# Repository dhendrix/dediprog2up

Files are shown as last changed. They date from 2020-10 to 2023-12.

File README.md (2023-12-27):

# dediprog2up

This is an adapter intended to make firmware development easier on UP Xtreme
and UP Squared motherboards using Dediprog SF600 and EM100.

This project started as I was thinking about playing with the system firmware
(BIOS) on the UP Xtreme and trying to do a coreboot port. I had limited success
at creating a custom cable with a 12-pin header on one side and a 20-pin header
on the other to fit on a [Dediprog
ADP-SF600-254-TO-127-CB](https://www.dediprog.com/product/ADP-SF600-254-TO-127-CB).
It was difficult to split a fine-pitch ribbon cable and when I finally got one
working it could only operate at 1.5MHz.

Using this adapter board I was able to read and write the ROM using an SF600 at
24MHz, which is also fast enough to use an EM100 for SPI flash emulation.

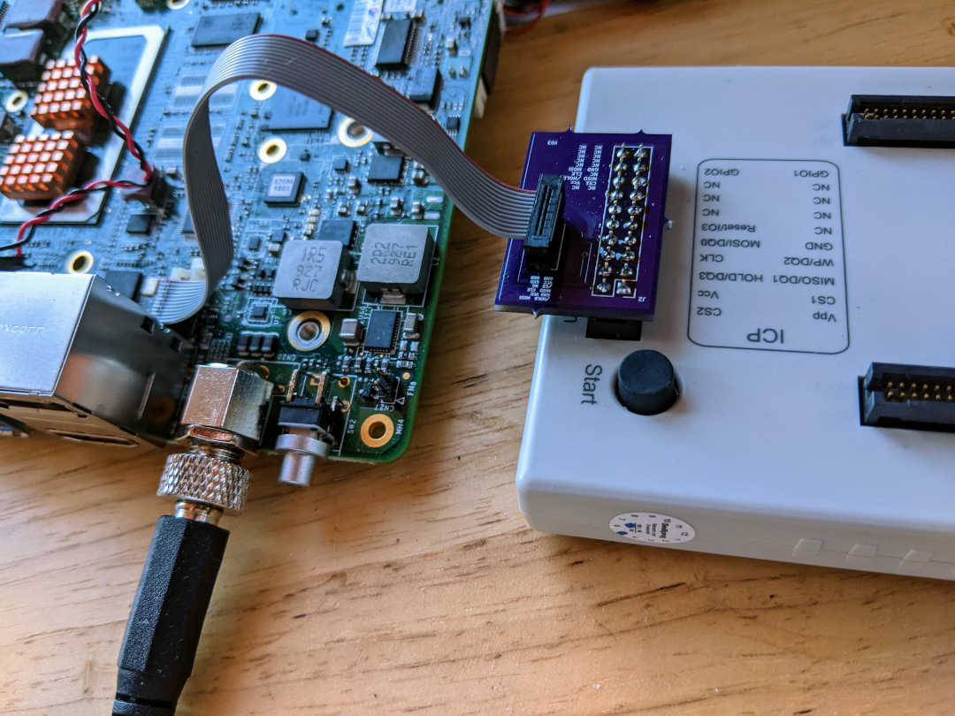
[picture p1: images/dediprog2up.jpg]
Action shot


## Pinout
### UP

The UP wiki has a good diagram of the header:
https://wiki.up-community.org/BIOS_chip_flashing_on_UP_Squared

I probed all the pins to verify the UP wiki's pinout. I'm still not sure which
pin is write-protect or if the extra 4 pins are used for anything (the flash
chip only has 8 pins), so if you happen to know feel free to send a PR to
update this README or file an issue to let me know!

The header is 2x6, pitch is 1.27mm.

Pin | Signal | Signal | Pin
:-: | :----: | :----: | :--:
1   |  GND   |  GND   |  2
3   |  GND   |  VCC   |  4
5   |  VCC   |  /CS   |  6
7   |  CLK   |  MISO  |  8
9   |  VCC   |  GND   | 10
11  | MOSI   |  /HOLD | 12

### Dediprog SF600/EM100

The header is 2x10, pitch is 2.54mm

The pinout is printed on the device, but here is a simplified version for our
purposes:

Pin | Signal | Signal | Pin
:-: | :----: | :----: | :--:
1   |  NC    |    NC  |  2
3   |  /CS   |   VCC  |  4
5   |  MISO  | /HOLD  |  6
7   |  NC    |   CLK  |  8
9   |  GND   |  MOSI  | 10
11  |  NC    |    NC  | 12
13  |  NC    |    NC  | 14
15  |  NC    |    NC  | 16
17  |  NC    |    NC  | 18
19  |  NC    |    NC  | 20

## Fabricating the adapter

There are a few online PCB fabrication companies. For this project I used
Oshpark since they make it super-easy to order boards that were made with
KiCad. Just upload the .kicad_pcb file to their website and they'll do the
rest.

Here is a project page at Oshpark where you can order directly:
https://oshpark.com/shared_projects/HCAx2AVW

## Additional Parts
### Headers

12-pin header to plug cable into:
https://www.chipquik.com/store/product_info.php?products_id=1900044

20-pin connector to plug into SF600/EM100:
https://www.digikey.com/en/products/detail/sullins-connector-solutions/SFH11-PBPC-D10-ST-BK/1990090

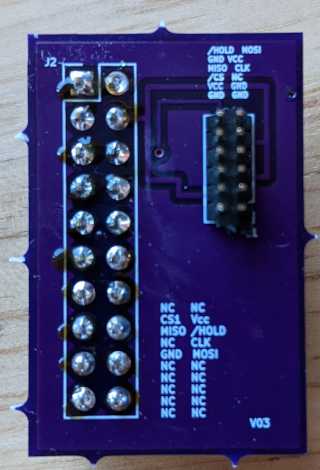
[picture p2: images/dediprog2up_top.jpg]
Top with headers soldered on


Top view with headers soldered on

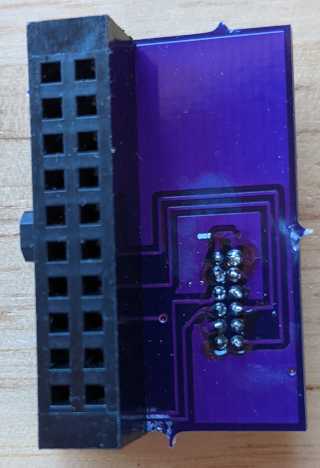
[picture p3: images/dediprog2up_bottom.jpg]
Bottom with headers soldered on


Bottom view with headers soldered on

### Cable

One thing to keep in mind when working with SPI flash is that shorter cables
are better. Up to 4 inches / 10 centimeters is generally OK, but above that you
may need to slow down your programmer's clock frequency. If you can use a
shorter cable then it's recommended that you do so.

The UP Xtreme's pin header is squeezed in between the HDMI/DP connector and the
RTC battery header. You'll likely need to cut (e.g. using a Dremel) the sides
of the receptacle on one end of the cable - be sure you do so on the side that
plug into the board. This unfortunately makes it easy for the receptacle to
fall apart, so be careful when handling the cable once it's plugged in.

#### Premade cables

12-pin 1.27mm pitch cables are somewhat rare and expensive, but come with some
assurance of quality so it's not a bad idea to have one.

Here is a pre-made cable on Mouser:
https://www.mouser.com/ProductDetail/200-FFSD06D04.0001N

#### DIY cables

It's somewhat easier to find the parts needed to make a 12-pin 1.27mm pitch
cable than finding a premade cable.

Ribbon cable:
https://www.mouser.com/ProductDetail/Wurth-Elektronik/63911215521CAB?qs=rrS6PyfT74fhArRJ3tCNFA%3D%3D

IDC header:
https://www.mouser.com/ProductDetail/Harwin/M50-3300642?qs=lPIp2VBpF5j6R5jWq4Rd4A%3D%3D

## Flash Chip

The flash chip on the UP Xtreme is a 1.8V W25Q256JWEQ. The flash chip on the UP
Squared is a 1.8V W25Q128FW (according to the UP Wiki).

I've been able to successfully read it at 24MHz which is the highest speed the
SF600 supports. It is recommended to read the chip several times and diff the
output to ensure consistent readings.  Inconsistent readings may indicate that
your cable is too long or that there is a quality issue with your cable or
soldering.

Here is how to read it using flashrom:

	flashrom -p dediprog:voltage=1.8,spispeed=24M -r foo.bin

# Related projects

* A similar adapter for UP boards intended to work with Dediprog hardware:
  https://github.com/skiselev/up-dediprog-adapter

* The qspimux project has adapters for several popular NOR flash sockets and
  adds isolatation circuitry to eliminate potential errors while also making it
  suitable for programmers that are always-on:
  https://github.com/felixheld/qspimux

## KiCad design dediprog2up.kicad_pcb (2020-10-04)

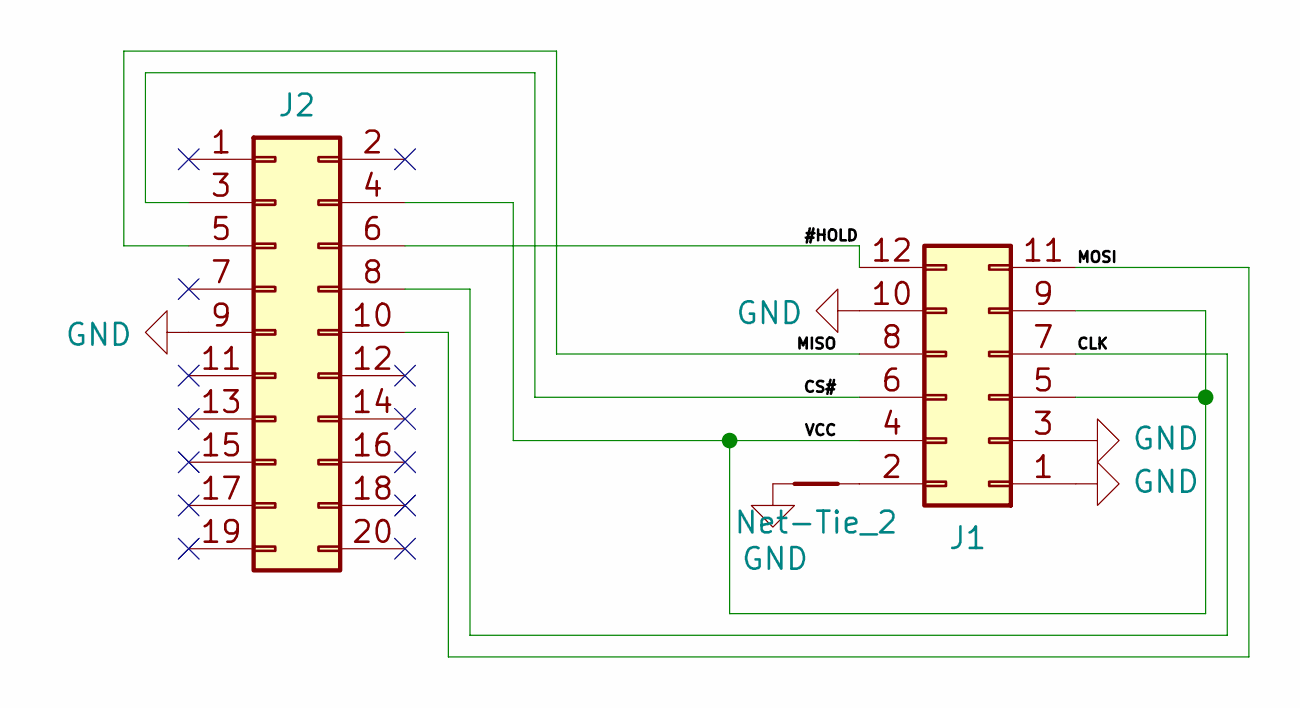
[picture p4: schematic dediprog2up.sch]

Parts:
GND1: Net-Tie_2; NetTie-2_SMD_Pad0.5mm
J1: Conn_02x6_Odd_Even; PinHeader_2x06_P1.27mm_Vertical
J2: Conn_02x10_Odd_Even; PinHeader_2x10_P2.54mm_Vertical

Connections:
/#HOLD: J1.12, J2.6
/CLK: J1.7, J2.8
/CS#: J1.6, J2.3
/MISO: J1.8, J2.5
/MOSI: J1.11, J2.10
/VCC: J1.4, J1.5, J1.9, J2.4
GND: GND1.2, J1.1, J1.3, J1.10, J2.9
unnamed: GND1.1, J1.2

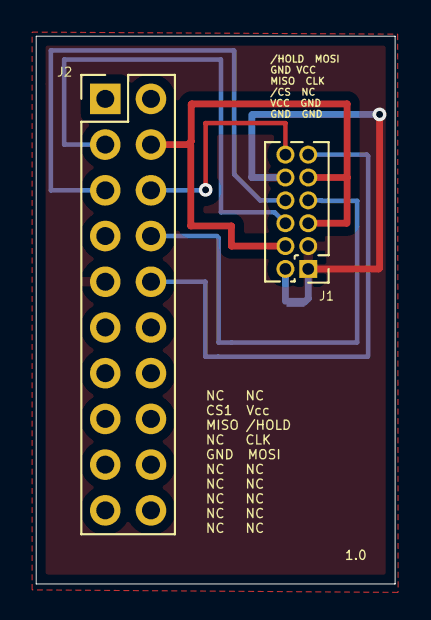
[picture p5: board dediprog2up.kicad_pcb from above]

Board: 2 copper layers, 19.9 x 30.4 mm, 3 parts (1 on the bottom side), 8 nets.

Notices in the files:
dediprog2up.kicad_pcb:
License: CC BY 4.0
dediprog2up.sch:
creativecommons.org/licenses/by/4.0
